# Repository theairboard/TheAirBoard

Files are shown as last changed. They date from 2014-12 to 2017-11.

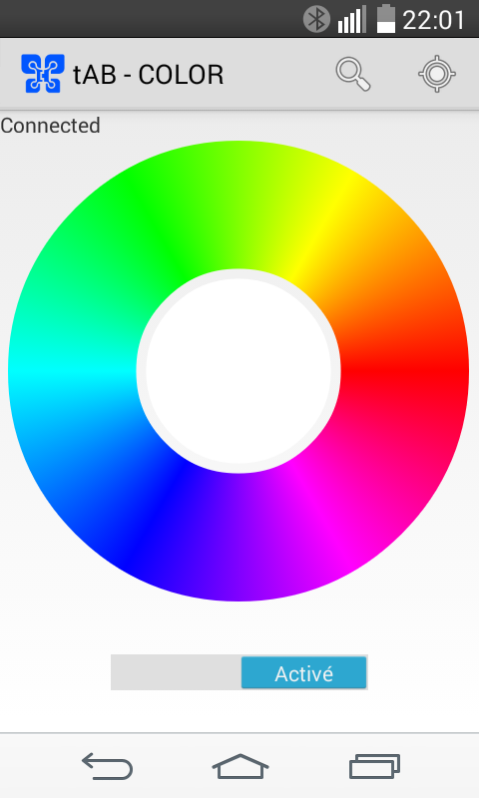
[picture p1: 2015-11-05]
android/tAB-Color/tAB-COLOR.png

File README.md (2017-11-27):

[The AirBoard: sketch everyware](http://www.theairboard.cc)
=============================================
[order yours now](http://sales.theairboard.cc)
The AirBoard pinout

Summary
-------
The AirBoard is a wireless, modular and ultra low-power Arduino prototyping platform for the Internet of Things, designed to explore, hack and deploy your killer idea in the field.

<b>Note:</b> The AirBoard is CE certified and comes with a UL1642, CB/IEC62133, UN38.3 fully certified built-in battery.

<b>Note:</b> The AirBoard has been designed to be wirelessly reprogrammable. The microUSB connector is used for battery charging only. To upload a new program, you will need additional wireless shields such as XBee or BLE and their associated USB dongle, or an external serial connection over FTDI.

Features
-----------
<b>Go wireless</b><br>
Explore the hotest wireless technologies today: with its popular Bee form factor, the AirBoard features a socket for XBee, Bluetooth, BLE and WiFi wireless shields, as well as the recent GSM/GPRS, SIGFOX and LoRa WAN long range IoT modules. Simply swap the radio for instant communication and WPAN Over-The-Air Programming.<br>
<br>
<b>Iterate quickly</b><br>
The AirBoard was designed with productivity in mind. Design and iterate quickly with the built-in open solderless breadboard. Only Arduino’s most popular I/Os are exposed, in order to lower the cognitive barrier and encourage the highest experiment turnover. Snap in hundreds of sensors and experiment a whole library of interactions in just seconds.<br>
<br>
<b>Deploy your device in the field</b><br>
Beyond the Internet of Things, ubiquitous devices require efficient Power and Data Management strategies to become truly autonomous.<br>
<br>
<b>Ultra Power Efficient</b><br>
Forget about your sensors with the built-in battery and Power Management System. The AirBoard is designed for ultra low-power applications, yet capable to drive long range wireless shields. It offers an ultra-low power sleep mode with switchable radio for most efficient communication strategy.<br>
<br>
<b>Your first sketch in seconds</b><br>
Start programming straight from the box with this superb web IDE by codebender. All required libraries and quick start source codes have been installed already. And with the pre-loaded Arduino Fio bootloader, you can also use the Arduino IDE. So why don’t you wait and start sketching now!<br>
<br>
<b>Make your own App</b><br>
It’s no longer needed to be an expert in programming to build pretty AND functional Graphical User Interfaces. Have fun interacting with your tangible hardware right away! Just drag and drop a whole library of widgets to build your own mobile app. remotexy and Blynk work seamlessly with the AirBoard and are great examples of bringing rapid prototyping to everyone.<br>

Specification
-------------

<b>Size and Weight</b>

    41x25x9mm
    Weight, including battery: 10g

<b>Native Arduino Processor</b>

    Arduino compatible
    ATmega328P processor @ 8MHz
    Pre-loaded Arduino Fio bootloader
    Arduino IDE support
    codebender web IDE support

<b>Open solderless breadboard and socket headers</b>

    7x GPIO, I2C, SPI, 2x 10-bit ADC, 3x PWM
    5VUSB/500mA, 3.3V/200mA power outputs
    Up to 18x GPIOs, 6x 10-bit analog inputs or 6x PWMs

<b>Bright RGB LED</b>

    RGB LED, up to 2240mcd, 120° viewing angle

<b>Wireless</b>

    « Bee » socket form factor
    Wireless support: XBee, Bluetooth 2.1,  Bluetooth Low Energy 4.0, WiFi,GSM/GPRS, SIGFOX, LoRa WAN
    2-channel Over-The-Air Programming (OTAP)
    5-second programming via XBee, Bluetooth, WiFi

<b>Ultra Low Power Management System</b>

    155mAh rechargeable lithium-ion battery
    1A switchable RF LDO
    330nA system deep sleep
    Autonomy in sleep mode: 2-3 years
    Autonomy in communication: 6 months (XBee 1 data/minute)

<b>Built-in battery charger</b>

    1-cell Li-ion USB charger
    Battery Over Current, Charge & Discharge protect
    Battery level indicator, charge status, USB voltage monitor
    Charge time: 1.5 hours

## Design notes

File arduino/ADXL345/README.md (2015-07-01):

##Accelerometer_ADXL345


This is a high resolution digital accelerometer providing you at max 3.9mg/LSB resolution and large ±16g measurement range. It's base on an advanced 3-axis IC ADXL345. Have no worry to implement it into your free-fall detection project, cause it's robust enough to survive upto 10,000g shock. Meanwhile, it's agile enough to detect single and double taps.It's ideal for motion detection, Gesture detection as well as robotics.

For more information, please refer to [Grove_3Axis_Digital_Accelerometer_ADXL345][1]

----
This software is written by Frankie Chu for seeed studio<br>
and is licensed under [The MIT License](http://opensource.org/licenses/mit-license.php). Check License.txt for more information.<br>

Contributing to this software is warmly welcomed. You can do this basically by<br>
[forking](https://help.github.com/articles/fork-a-repo), committing modifications and then [pulling requests](https://help.github.com/articles/using-pull-requests) (follow the links above<br>
for operating guide). Adding change log and your contact into file header is encouraged.<br>
Thanks for your contribution.

Seeed is a hardware innovation platform for makers to grow inspirations into differentiating products. By working closely with technology providers of all scale, Seeed provides accessible technologies with quality, speed and supply chain knowledge. When prototypes are ready to iterate, Seeed helps productize 1 to 1,000 pcs using in-house engineering, supply chain management and agile manufacture forces. Seeed also team up with incubators, Chinese tech ecosystem, investors and distribution channels to portal Maker startups beyond.

[1]: http://www.seeedstudio.com/wiki/Grove_-_3-Axis_Digital_Accelerometer(%C2%B116g)

Analytics (https://github.com/igrigorik/ga-beacon)

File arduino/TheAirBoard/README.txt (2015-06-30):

The AirBoard is a thumb-size, Arduino-compatible, wireless, low-power,
ubiquitous computer designed to sketch Internet-of-Things, fast!
Visit http://www.theairboard.cc
Upload your first sketch in seconds from https://codebender.cc?referral_code=Ub56L825Qb

Developing off-line:
- Download the Arduino IDE from http://www.arduino.cc/en/Main/Software
- Place /TheAirBoard folder in your Preferences>Sketchbook location /libraries folder.
- You may need to create the /libraries subfolder if it is your first library.
- Restart the Arduino IDE.
- Select Tools>Board>Arduino Fio in the Arduino IDE.

Programming via Bluetooth or XBee:
- With Bluetooth, first pair your-device
- Select Tools>Serial Port>your-device in the Arduino IDE.

Programming via WiFi:
- Disconnect from any wired or wireles networks.
- Connect to the adhoc WiFi WiFly/RN-171 network.
- Compile and locate your .hex file.
- Edit and update the WiFi upload script.scpt with your .hex file path and name.
- Launch the WiFi upload script.scpt AppleScript to upload the .hex file.

Check license.txt for more information
All text above must be included in any redistribution

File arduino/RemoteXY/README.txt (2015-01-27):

  This library for remote control Arduino from 
  smartphone or tablet 

  Download the Android app from the 
  website: http://remotexy.com/download/ for connect this library.
    
  Use the website http://remotexy.com/ to create your own management 
  interface your arduino with your smartphone or tablet.
  You can create different management interfaces. Use buttons, 
  switches, sliders, joysticks (g-sensor) all colors and sizes 
  in its interface. Next, you will be able to get the sample 
  code for arduino to use your interface for control from a 
  smartphone or tablet. You will not need to re-install the 
  android app, as it will determine which interface you have 
  downloaded the arduino.

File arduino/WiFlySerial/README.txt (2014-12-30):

WiFly Driver for the Arduino platform
Provides WiFi wireless communications for Arduino-based systems.
Arduino 1.0 platform

============
TRADEMARKS
============
"WiFly", "RN-131","RN-171", "RN-174", "RN-XV" are trademarks / tradenames of Roving Networks Inc.
"Arduino" is a trademark of Arduino LLC.
Other trademarks referenced are the property of their respective owners.

============
LICENSE
============

(C) 2011, 2012 Tom Waldock

   Permission is hereby granted, free of charge, to any person
   obtaining a copy of this software and associated documentation
   files (the "Software"), to deal in the Software without
   restriction, including without limitation the rights to use, copy,
   modify, merge, publish, distribute, sublicense, and/or sell copies
   of the Software, and to permit persons to whom the Software is
   furnished to do so, subject to the following conditions:

   The above copyright notice and this permission notice shall be
   included in all copies or substantial portions of the Software.

   THE SOFTWARE IS PROVIDED "AS IS", WITHOUT WARRANTY OF ANY KIND,
   EXPRESS OR IMPLIED, INCLUDING BUT NOT LIMITED TO THE WARRANTIES OF
   MERCHANTABILITY, FITNESS FOR A PARTICULAR PURPOSE AND
   NONINFRINGEMENT. IN NO EVENT SHALL THE AUTHORS OR COPYRIGHT HOLDERS
   BE LIABLE FOR ANY CLAIM, DAMAGES OR OTHER LIABILITY, WHETHER IN AN
   ACTION OF CONTRACT, TORT OR OTHERWISE, ARISING FROM, OUT OF OR IN
   CONNECTION WITH THE SOFTWARE OR THE USE OR OTHER DEALINGS IN THE
   SOFTWARE.

============
INSTALLATION
============

Library version:
Copy the WiFlySerial files and Examples folders to a new folder in your Arduino Libraries path
(e.g. /usr/share/arduino/libraries/WiFlySerial)
Restart the IDE; the examples and libraries should then become available.
Also: install Streaming.h, PString.h from arduiana.org, and Time.h from arduino.cc/libraries

WebTimeA1.ino is a simple example webserver that shows the current time.
Aim your browser at the Arduino+WiFly's IP address for the current UTC time.
Add "/status" to the URL for additional status items, or "/auto" for 30-second refreshes.

WiFly_TestA1.ino is a simple terminal for communicating to and from the WiFly.
It is useful for exploring its features and debugging issues.

WFSv3 is a proof-of-concept demo of Client/Server libraries based on the Arduino EthernetServer and EthernetClient models.

=======
SUPPORT
=======

Current code and support forums are available from http://arduinowifly.sourceforge.net.
Additional commentary on http://arduinology.blogspot.com and http://arduinology.tumblr.com

=======
HISTORY
=======
*** 2012-May-05 1.08 Minor fix to setRemotePort();
*** 2012-Apr-22 1.07 Time sync handling improvements and Client/Server library compilation issue resolved.

*** 2012-Apr-14 1.06 Clean closing and faster data->command mode switching.
    Preview of Client/Server libraries

*** 2012-Mar-22 1.05 Noise reduction
   Miscellaneous stabilizations, cleanups and now finishes sending before listening.

*** 2012-Feb-25 1.03 - Arduino 1.0 compatible (as are future versions)
   Implemented serial functions available(), peek(), read(), flush(), write() to replace direct uart calls.
   read() now watches for in-stream command signals especially *CLOS*.
   uart will become private in an upcoming release.

*** 2012-Feb-24 1.02 beta released - Arduino 1.0 compatible
   closeCommand() now avoids calling close command if TCP connection already closed.
   WebClientGetPost returned to Examples.

*** 2012-Feb-22 1.01 beta released - Arduino 1.0 compatible.
   Buffer-overflow condition removed from core routines - stability improved.
   Debug methods altered to streaming form.
   Replaced hard-coded timing values with defines.

*** 2012-Feb-18 Arduino 1.0-compatible version released.

Arduino 1.0 compatibility changes
   NewSoftSerial replaced by SoftwareSerial.
   F() available, although GetBuffer_P() continues in legacy usage.
   Time.h to current version.
   PString.h to current version.
   Streaming.h to current version.

Memory handling changes, reduced footprint
   Methods now create (and release) their own buffers as needed, 
    no longer borrowing & over-writing provided buffers.
   Strings moved to static (program) space
   Some functions using only 20-byte command buffers instead of 64-byte or larger.

Added status methods
   IsConnected renamed to isifUp()
   getDeviceStatus() retrieves a status byte interpretable with is...() methods.  
   Reduces impact on WiFly during status interrogations.
   See isAssociated() isTCPConnected(), isAuthenticated(), isDNSfound() et al.
   isInCommandMode() and isConnectionOpen() exposed and internal flags made private.
   ScanForPattern watches for *OPEN* and *CLOSED* signals.  
     *** once streaming enabled, the uart will also catch these.

Naming Changes
   Method names are now more consistently camel-case.  Some sketches may break and require updates.  Sorry.

Added server, port, UDP methods
   New methods added to better support server mode, port definitions, and protocol (TCP/UDP) changeover.
   Simplifies waiting for connections, setting of ports and protocols.

Added WiFi configuration methods
   New methods for configuring Ad-hoc/Infrastructure modes, authentication modes, and DHCP options.

Utility Functions
   New methods provided for conversion between IP addresses represented in strings and byte arrays.
   
Bugs:
   Some fixed.
   Others added.  Please see support forums for bug topics!

Known issues:
   1. With WiFly 2.32 occasional difficulties getting Arduino - WiFly communications to solidify within first attempts... Sometimes it cycles a few times prior to settling down.  Comments and experiences welcome.
   2. closeConnection() does so successfully but WiFly also reports an error.
   3. Keep > 150 bytes free RAM for WiFlySerial buffer allocation/release operations.
   4. Keep baud speeds down to 9600 for now.  Faster may well be possible.

*** 2011-Apr-07 Removed bug in ExtractDetail introduced yesterday.

*** Initial library release.

2011-Apr-06 Added status methods, corrected memory handling, re-packaged for library.

*** Initial release.

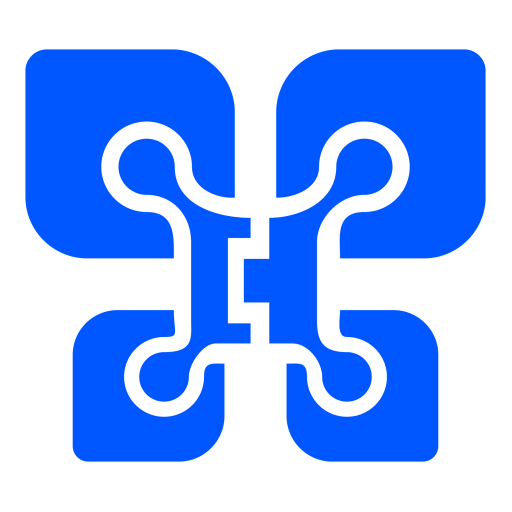
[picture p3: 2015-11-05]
android/tAB-Direction/ic_launcher-web.png

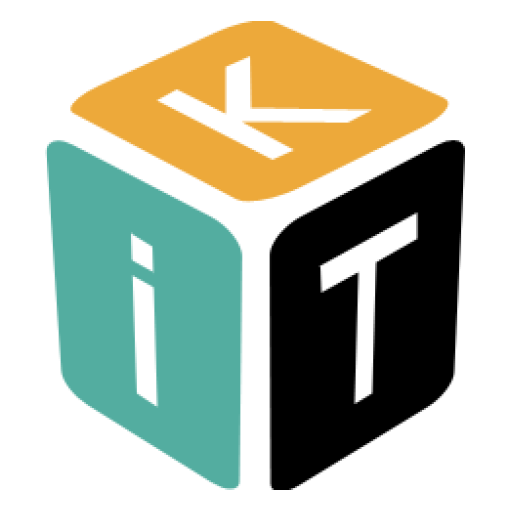
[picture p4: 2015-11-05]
android/tAB-ColorButtons/ic_launcher-web.png

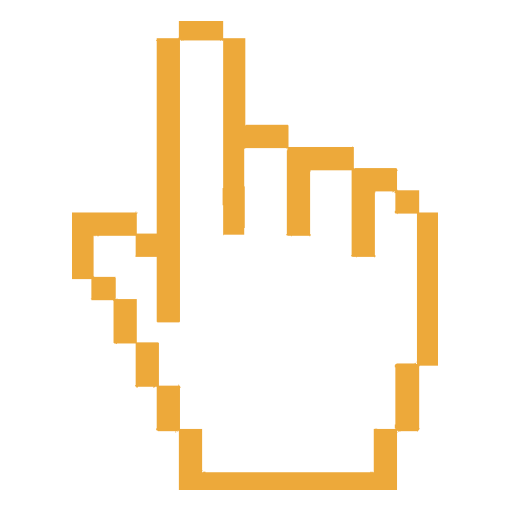
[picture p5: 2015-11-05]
android/tAB-ColorButtons/ic_hand-web.png

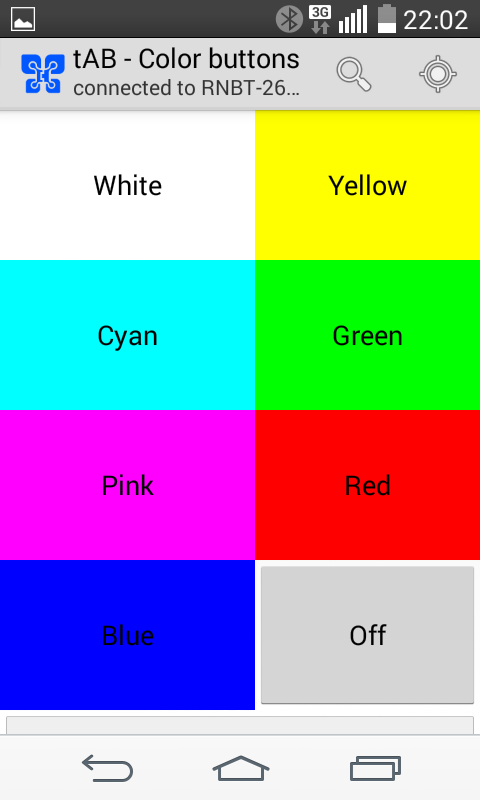
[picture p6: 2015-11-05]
android/tAB-ColorButtons/tAB-ColorButtons.png

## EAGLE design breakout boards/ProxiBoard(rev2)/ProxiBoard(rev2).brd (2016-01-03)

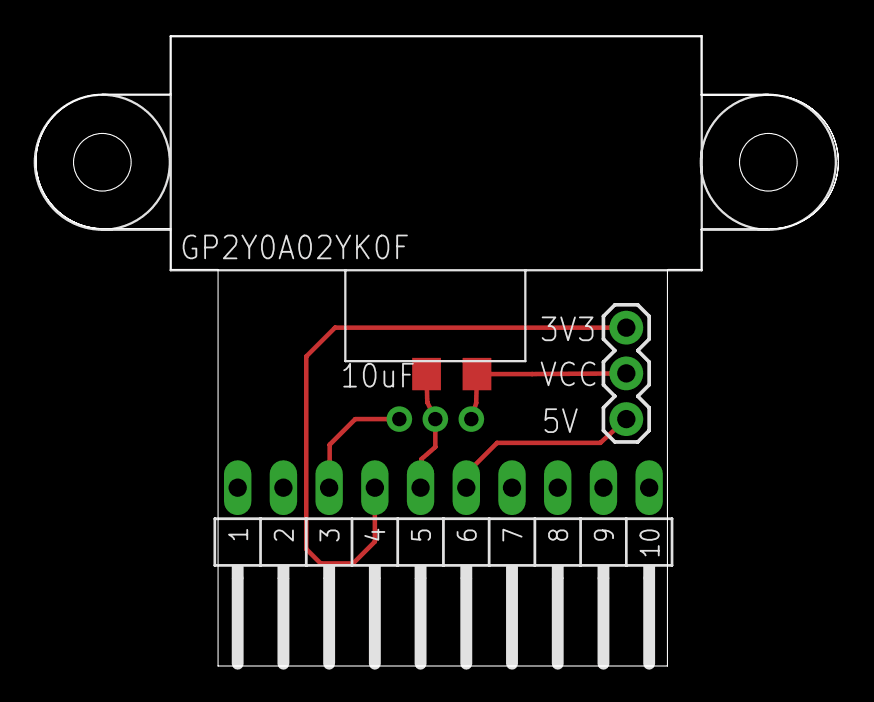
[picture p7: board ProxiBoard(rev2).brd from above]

Board: 2 copper layers, 44.6 x 35.0 mm, 5 parts (0 on the bottom side), 5 nets.

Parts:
C1: 10uF; 1206
FRAME1: SCH_FRAME; BOARD_FRAME
JP1: SIL; SIL10-2.54MM
JP2: 1X03
U1: GP2Y0A02YK0F

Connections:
3V3: JP1.4, JP2.3
5V: JP1.6, JP2.1
A4: JP1.3, U1.1
unnamed: C1.1, JP2.2, U1.3
unnamed: C1.2, JP1.5, U1.2

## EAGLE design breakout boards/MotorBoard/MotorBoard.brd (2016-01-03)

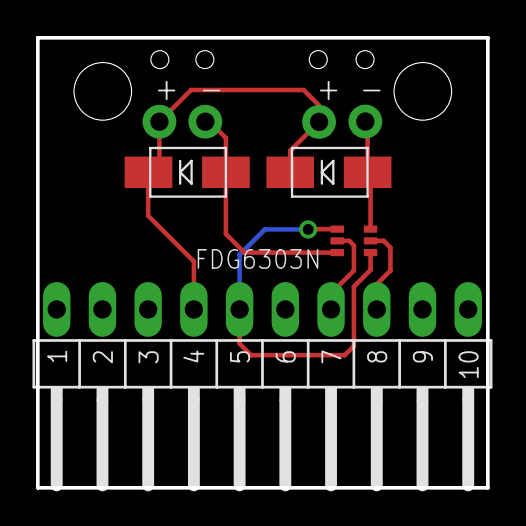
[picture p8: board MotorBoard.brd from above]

Board: 2 copper layers, 25.0 x 25.0 mm, 10 parts (0 on the bottom side), 6 nets.

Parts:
D1, D2: S1M; DO-214AC
FRAME1: SCH_FRAME; BOARD_FRAME
JP1: SIL; SIL10-2.54MM
JP2, JP3, JP4, JP5: M01SMDNS; 1X01NS
Q1: FDG6303N; SC70-6
U$1: LAYOUT25X25

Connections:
GND: JP1.5, Q1.1, Q1.4
unnamed: JP1.7, Q1.5
unnamed: JP1.8, Q1.2
unnamed: D2.1, JP4.1, Q1.6
unnamed: D1.1, JP2.1, Q1.3
VCC: D1.2, D2.2, JP1.4, JP3.1, JP5.1

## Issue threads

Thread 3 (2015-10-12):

Compability with Bluetooth module

jujumoz, 2015-10-12:
Hi,

I just received my airboard, thanks a lot.
I just asking myself how can I upload sketch on it if I don't have the wifi or xbee module you sent with some package ? I have a hc 06 bluetooth module, can I use it as well ?
If yes, how ?
Thanks a lot.

theairboard, 2015-10-12:
To upload wirelessly, you need remote RTS/DTR flow control which doesn't seem to be implemented on hc 06.
RN41, RN42, BLE-LINK, Bluefruit EZ-Link, XBee and WiFly for instance can provide remote flow control.

Closed 2016-03-17.

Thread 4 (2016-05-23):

How to upload a sketch with BT BlueSmurf Gold?

seinecle, 2016-05-23:
My USB module is BlueSMurf:
https://learn.sparkfun.com/tutorials/using-the-bluesmirf

I plugged it to the Airboard:
Vcc to 5V
Grd to Grd
TX-0 to D12
RX-1 to D3~

I have installed a BT dongle on my PC, and I paired the BlueSmirf with the dongle. When I open a serial monitor, it says the ports are busy. Any help on this issue? Just trying to upload a sketch to the Airboard...

theairboard, 2016-05-28:
This module seems to lack the critical pin "Remote RTS/PIO10" of RN41/42
for programming, so I'm afraid it is unsuitable for OTAP. Use RN41/42-XVP
instead. Best, Olivier
Le 23 mai 2016 17:40, "Clement Levallois" <notifications@github.com> a
écrit :

My USB module is BlueSMurf:
https://learn.sparkfun.com/tutorials/using-the-bluesmirf

I plugged it to the Airboard:
Vcc to 5V
Grd to Grd
TX-0 to D12
RX-1 to D3~

I have installed a BT dongle on my PC, and I paired the BlueSmirf with the
dongle. When I open a serial monitor, it says the ports are busy. Any help
on this issue? Just trying to upload a sketch to the Airboard...

—
You are receiving this because you are subscribed to this thread.
Reply to this email directly or view it on GitHub
<https://github.com/theairboard/TheAirBoard/issues/4>

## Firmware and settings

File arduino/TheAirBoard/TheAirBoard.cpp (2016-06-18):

/*******************************************************************************
This is The AirBoard utility library.
Revision 2.0, April 09, 2016
- in powerDown function, added 1ms delay to allow MCU to recover from sleep
Revision 2.1, April 25, 2016
- in configRN42 function, doubled delay between commands
Revision 2.2, June 18, 2016
- in powerDown function, changed baudrate restoration method upon recover from sleep
- added getTemp function to return internal MCU temperature in °C

The AirBoard is a thumb-size, Arduino-compatible, wireless, low-power,
ubiquitous computer designed to sketch Internet-of-Things, fast!
Visit http://www.theairboard.cc
Upload your first sketch in seconds from https://codebender.cc?referral_code=Ub56L825Qb
Check README.txt and license.txt for more information.
All text above must be included in any redistribution.
*******************************************************************************/

#include <TheAirBoard.h>

/*******************************************************************************
 * Constructor : initialize utility library
 *******************************************************************************/
TheAirBoard::TheAirBoard(void) {
  digitalWrite(NCHG, HIGH);  // set internal pull-up for charge status
}

/*******************************************************************************
 * Power down processor
 * Don't forget to switch off the LED and the RF module for lowest consumption.
 * Board quiescent current budget:
 * charge circuit = 180 nA
 * ATmega328P deep sleep = 120 nA
 * regulators quiescent currents = 30 nA
 *******************************************************************************/
void TheAirBoard::powerDown() {
  Serial.flush();				   // flush uart
  Serial.end();					   // end communication
  digitalWrite(RX, LOW);           // reset internal pull-up serial link
  ADCSRA &= B01111111;             // disable ADC
  power_all_disable();
  /****************DON'T CHANGE************************************************/
  MCUCR = B01100000;               // BOD disable timed sequence
  MCUCR = B01000000;
  SMCR = B00000101;                // power down mode + sleep enable
  asm("sleep\n");
  sleep_disable();                 // first thing after wake up
  /****************************************************************************/
  power_all_enable();
  ADCSRA |= B10000000;             // enable ADC
  Serial.begin(U2X0?1000000/((UBRR0H<<8)+UBRR0L+1):500000/((UBRR0H<<8)+UBRR0L+1)); // restart uart with initial baudrate
}

/*******************************************************************************
 * Set watchdog timeout to the nearest value among:
 * 0.016, 0.032, 0.064, 0.125, 0.25, 0.5, 1.0, 2.0, 4.0, 8.0 seconds
 *******************************************************************************/
void TheAirBoard::setWatchdog(int period) {
  byte wdp;
  wdp = round(log(period/16)/log(2));
  wdp = wdp & B00000111 | (wdp & B00001000)<<2;
  MCUSR &= ~(1<<WDRF);             // clear reset flag
  WDTCSR |= (1<<WDCE) | (1<<WDE);  // in order to change WDE or the prescaler, we need to set WDCE (This will allow updates for 4 clock cycles)
  WDTCSR = wdp;					   // set watchdog prescaler
  WDTCSR |= _BV(WDIE);             // enable the WD interrupt (note no reset)
}

/*******************************************************************************
 * Battery check utility
 * - check battery voltage, USB voltage and charge status
 * - blink red/green while charging
 * - solid green when discharging or when charged
 * - solid red when battery low
 * - return battery voltage indicator
 *******************************************************************************/
#define REFRESH    500 // battery check and status refresh period in ms
#define LOWBAT     3.1 // battery low voltage threshold in V
#define VF         1.2 // SML-P11VT forward voltage in V (under current adjusted)

float TheAirBoard::batteryChk(void) {
  static unsigned long time;
  static float vbat;
  static boolean flag;
  boolean usbplug, batlow;
  
  if(millis() - time > REFRESH) {
    time = millis();
  
    usbplug = analogRead(VUSB) ? true:false;
    batlow = (vbat = 3.3*analogRead(VBAT)/1024 + VF) < LOWBAT ? true:false;
    
    if(usbplug) { // USB plugged in
      if(digitalRead(NCHG)) { // charged
        analogWrite(RED, 0);
        analogWrite(GREEN, 1);
      }
      else { // charging
         analogWrite(GREEN, flag^=1);
         analogWrite(RED, !flag);
      }
    }
    else { // no USB
      if(batlow) {
        analogWrite(RED, 1);
        analogWrite(GREEN, 0);
      }
      else {
        analogWrite(RED, 0);
        analogWrite(GREEN, 1);
      }
    }
  }
  
  return vbat;
}
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

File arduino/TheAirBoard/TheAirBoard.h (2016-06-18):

/*******************************************************************************
This is The AirBoard utility library.
Revision 2.2, June 18, 2016
- added getTemp function to return internal MCU temperature in °C

The AirBoard is a thumb-size, Arduino-compatible, wireless, low-power,
ubiquitous computer designed to sketch Internet-of-Things, fast!
Visit http://www.theairboard.cc
Upload your first sketch in seconds from https://codebender.cc?referral_code=Ub56L825Qb
Check README.txt and license.txt for more information.
All text above must be included in any redistribution.
*******************************************************************************/
 
#ifndef TheAirBoard_h
#define TheAirBoard_h
 
#include <Arduino.h>
#include <avr/sleep.h>
#include <avr/power.h>
#include <avr/wdt.h>
#include <math.h>

// The AirBoard pin mapping
#define RX		 0 // UART serial receive port
#define TX		 1 // UART serial transmit port
#define CTS		 2 // Bluetooth/WiFi UART CTS flow control
#define WFF		 4 // WiFi GPIO6 TCP connection status
#define GREEN	 5 // GREEN LED (PWM)
#define BLUE	 6 // BLUE LED (PWM)
#define BTF		 7 // Bluetooth connection status/WiFi GPIO4 association/authentification status
#define RTS		 8 // Bluetooth/WiFi UART RTS flow control
#define RED		 9 // RED LED (PWM)
#define RF		14 // RF power control pin
#define RSSI	15 // XBee RSSI RX Strength Signal Indicator/WiFi GPIO5 TCP connection trigger
#define GPIO8	16 // Bluetooth PIO10 UART DTR flow control/WiFi GPIO8 sleep trigger/XBee DO8* output/GPRSbee wakeup pin
#define NCHG	17 // battery charge status (0 = charging)
#define VUSB	A6 // USB voltage indicator
#define VBAT	A7 // battery voltage indicator

// XBee configuration roles
#define MASTER 1
#define SLAVE  0

class TheAirBoard
{
  public:
    TheAirBoard(void);
	void powerDown();
	void setWatchdog(int period);
	float batteryChk(void);
	void configXBee(boolean role);
	void configRN42();
	void configWiFly();
	double getTemp(void);
};

#endif

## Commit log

2014-11-30 The AirBoard library
    [Altimeter-Barometer.brd, Altimeter-Barometer.sch, Dual motor drive.brd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]
2014-11-30 Added baud rate parameter to powerDown function
2014-12-06 Proto boards library 0.1
    [Altimeter-Barometer.brd, Temperature-Humidity.brd]
2014-12-13 Added apk, stl and protoboard
    [TX433MHz.brd, theairboard.stl]
2014-12-21 Added GPS receiver
    [GPS receiver.brd]
2014-12-30 added Low-Power XBee and WiFi data logger examples
2015-01-03 - set green led value to minimum to avoid glare - completed firmware version for WiFi data logger
2015-01-24 Added draft schematics
    [Altimeter-Barometer.brd, GPS receiver.brd, TX433MHz.brd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]
2015-01-25 Added sample apps and code
    [theairboard.stl]
2015-01-27 Added RemoteXY sample code and lib
2015-01-29 Added Low-Power data logger, BLE app, OriginGPS
    [GPS receiver.brd]
2015-02-02 Added RemoteXY sample sketches
2015-02-07 Updated low-power figure
2015-02-14 Added DI-O library and sample code
2015-02-16 Added 433MHz transmitter
    [TX433MHz.brd]
2015-06-30 erase all
    [Dual motor drive.brd, GPS receiver.brd, Protoboard.brd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]
2015-06-30 Kickstarter commit
    [MotorBoard.brd, ProtoBoard.brd, ProxiBoard.brd]
2015-07-29 Update proximity sensor
2015-08-23 added Color example
    [MotorBoard.brd, ProtoBoard.brd, ProxiBoard.brd]
2015-12-24 corrected LoRa comment
    [MotorBoard.brd, ProtoBoard.brd, ProxiBoard.brd]
2016-01-03 updated breakout boards
    [MotorBoard.brd, ProtoBoard.brd, ProxiBoard(rev2).brd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]
2016-04-09 added power-up delay from sleep
2016-06-18 mod powerDown, add getTemp
    - in powerDown function, changed baudrate restoration method upon
    recover from sleep
    - added getTemp function to return internal MCU temperature in °C
2016-06-18 added getTemp function
    added getTemp function to return internal MCU temperature in °C

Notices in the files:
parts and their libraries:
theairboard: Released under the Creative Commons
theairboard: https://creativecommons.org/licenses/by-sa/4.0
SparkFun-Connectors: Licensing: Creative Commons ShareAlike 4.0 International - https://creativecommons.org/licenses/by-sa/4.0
